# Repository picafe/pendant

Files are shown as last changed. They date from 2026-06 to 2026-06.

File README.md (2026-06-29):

# Bicolor LED Pendant

A pendant built from two PCBs: a 8×8 bicolor LED matrix module (red, orange, green) and controller board with battery charging, USB-C power, 5 V boost, and motion sensing.

## Why I made this

I had already been working on a 32×8 bicolor matrix module and wanted to try the Pendant YSWS before the deadline. An example on the pendant website inspired me to make a bicolor version with an orange fire-style pattern. Fitting the full matrix and controller on one 2/4 layer board was not the most possible, so my design splits into a display PCB and a pendant controller, which are connected with 2.54mm pitch pin headers (likely just male machine pin headers soldered on both sides, since they have a larger spacing to accomodate for the inductor). There is also an accelerometer to have potential particle motion simulation.

## Photos

### 3D model

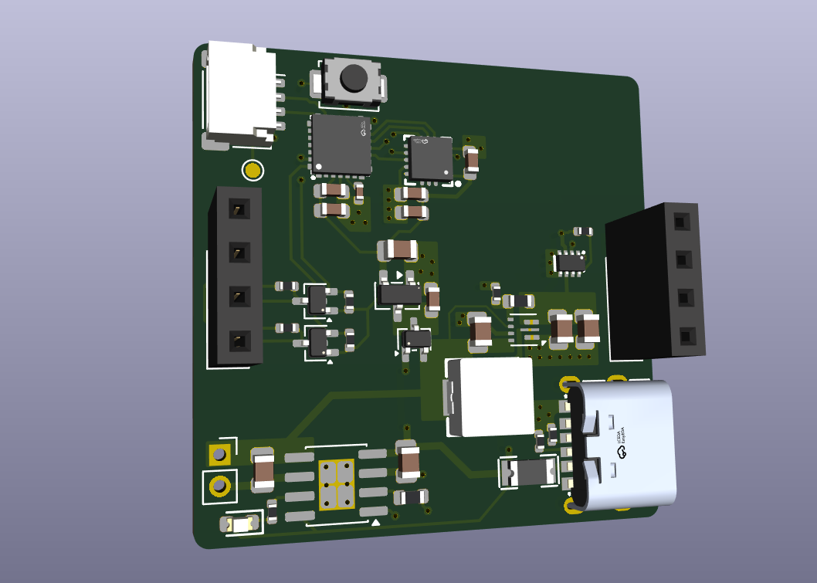
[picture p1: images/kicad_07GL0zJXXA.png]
Controller 3D model


### Schematic

**Controller**

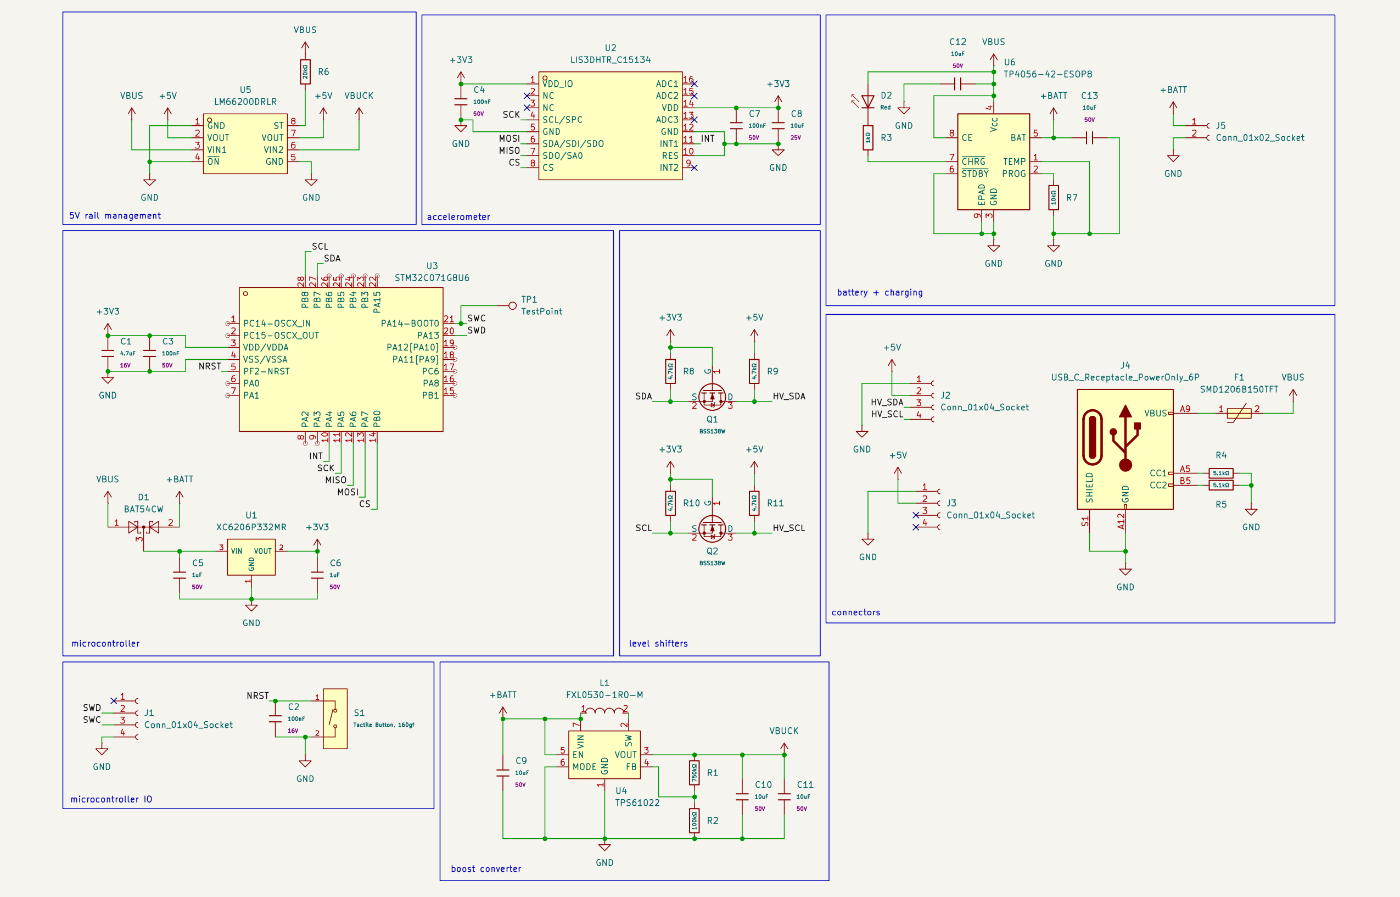
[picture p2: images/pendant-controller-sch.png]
Controller schematic


**Matrix**

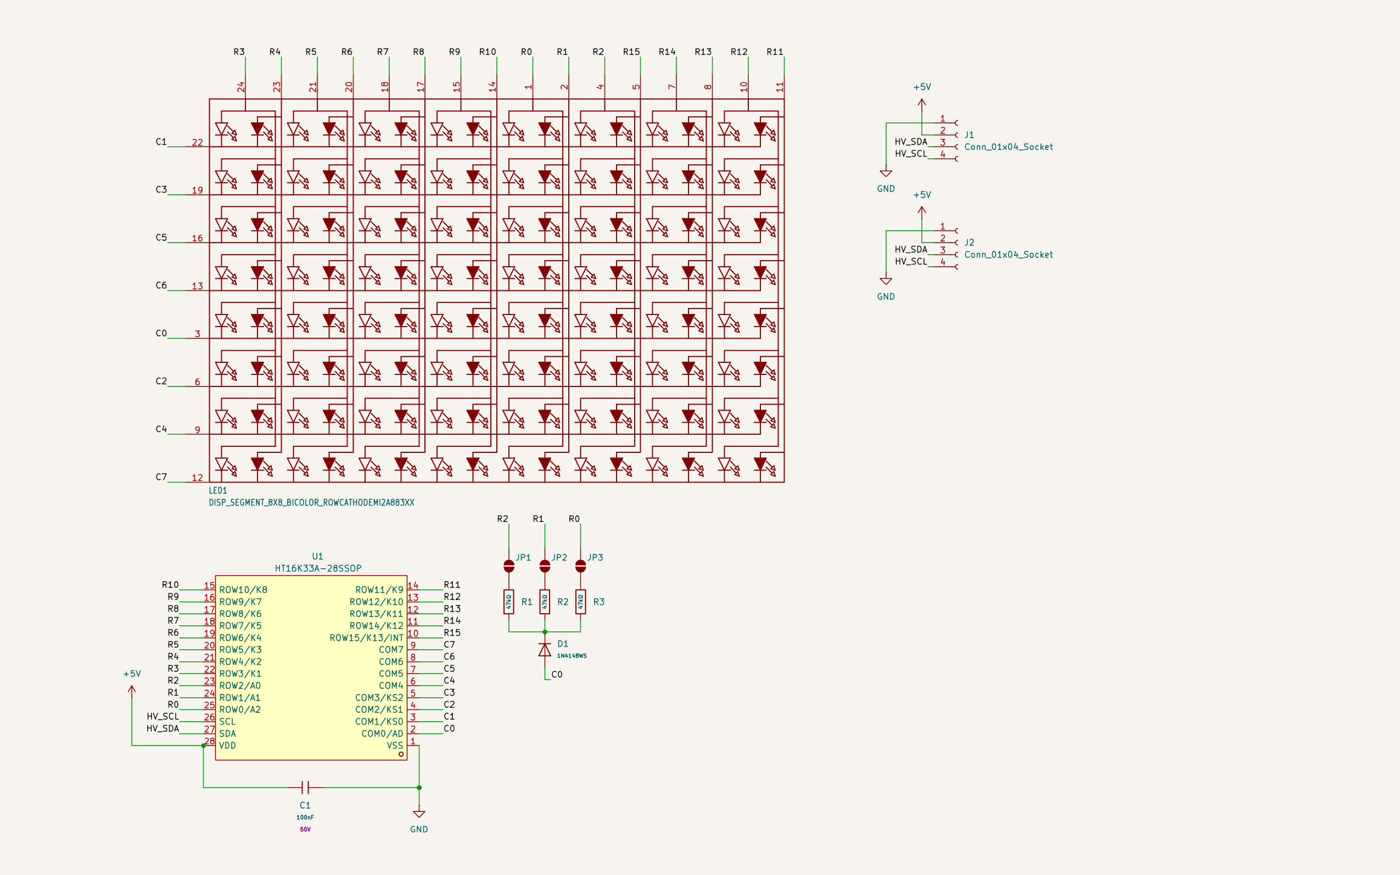
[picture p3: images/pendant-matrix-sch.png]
Matrix schematic


### PCB layouts

**Controller board**

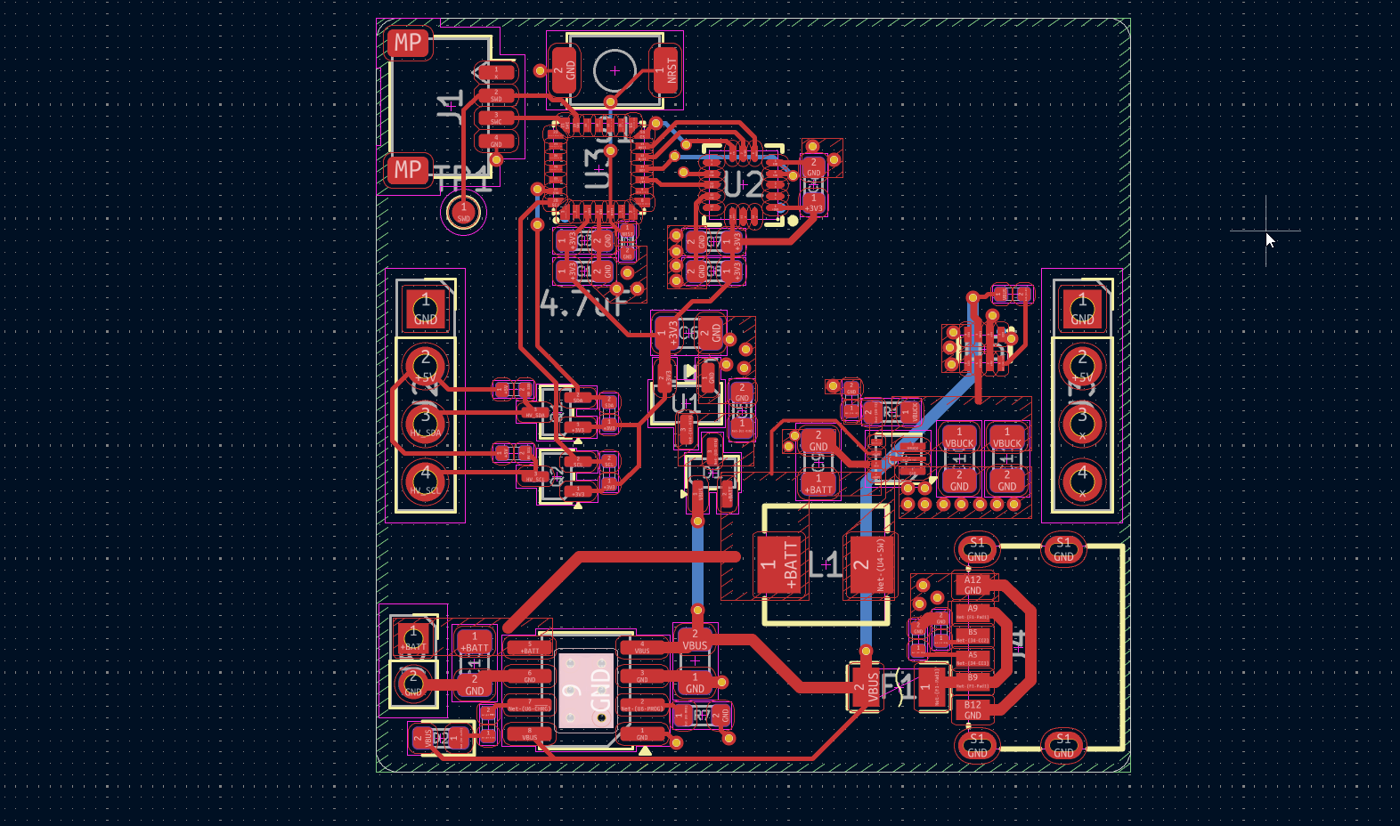
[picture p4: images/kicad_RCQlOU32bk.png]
Controller PCB routing


**Matrix module**

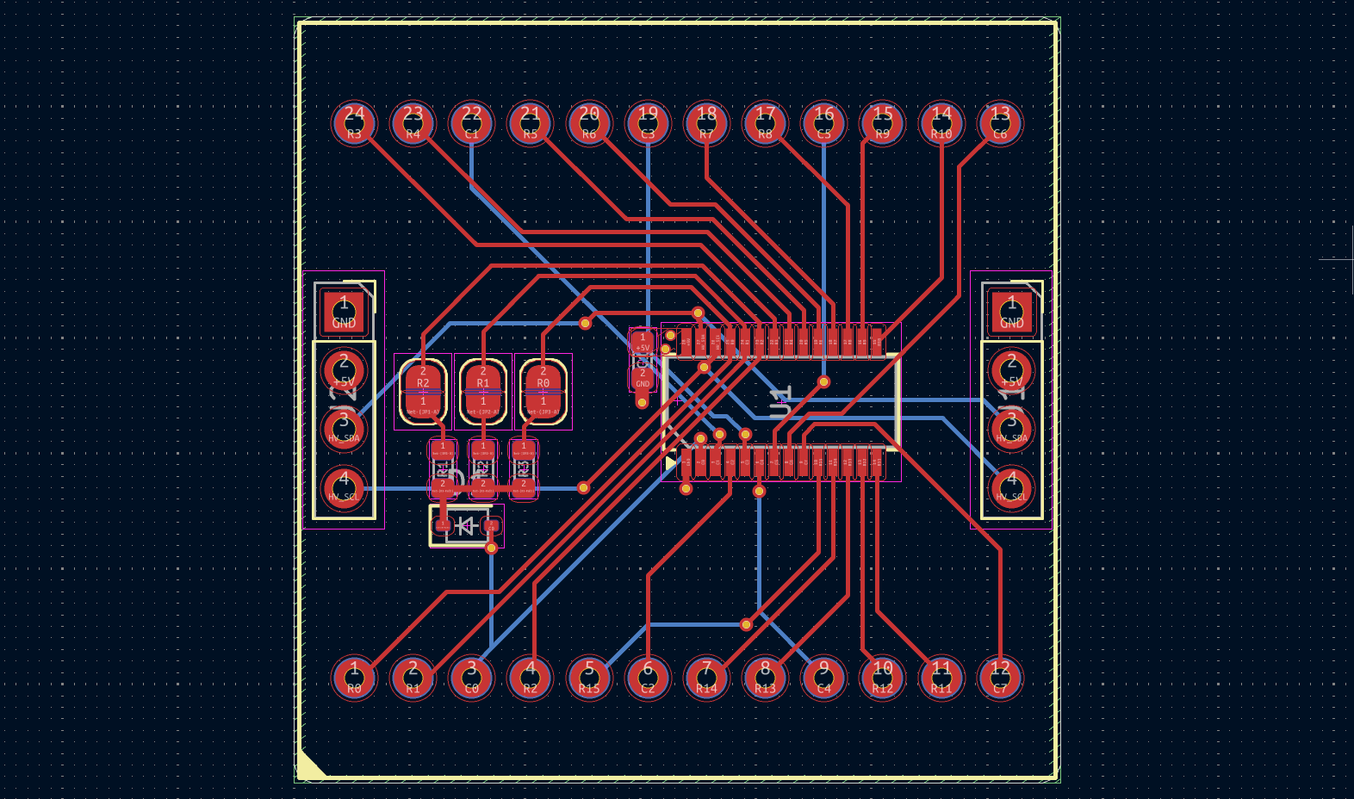
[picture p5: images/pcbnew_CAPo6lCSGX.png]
Matrix PCB layout


## Connections

All signals between the two boards are carried on PCB-mounted 2.54 mm pin headers. No off-board wiring is required beyond a LiPo cell on the controller.

## Bill of materials

Prices are per-unit LCSC values; standard connector values are estimated.

### Controller PCB

| Ref | Qty | Value | LCSC | Unit | Extended |
|-----|-----|---|---|---|---|
| U3 | 1 | STM32C071G8U6 | C44521811 | $1.67 | $1.67 |
| U4 | 1 | TPS61022 | C915088 | $1.32 | $1.32 |
| U5 | 1 | LIS2DW12TR | C189624 | $1.25 | $1.25 |
| U1 | 1 | XC6206P332MR | C5446 | $0.102 | $0.10 |
| U6 | 1 | TP4056-42-ESOP8 | C16581 | $0.19 | $0.19 |
| L1 | 1 | FXL0530-1R0-M | C475517 | $0.17 | $0.17 |
| Q1, Q2, Q3 | 3 | BSS138W | C28646265 | $0.025 | $0.08 |
| D1 | 1 | BAT54CW | C22392482 | $0.035 | $0.04 |
| D2 | 1 | Red LED | C2286 | $0.009 | $0.01 |
| D3 | 1 | SS34 | C8678 | $0.030 | $0.03 |
| F1 | 1 | SMD1206B150TFT | C269120 | $0.03 | $0.03 |
| S1 | 1 | Tactile button | C720477 | $0.053 | $0.05 |
| J4 | 1 | USB-C receptacle | C18357552 | $0.08 | $0.08 |
| J1 | 1 | JST-SH 4-pin | - | $0.08 *(est.)* | $0.08 |
| J2, J3 | 2 | 4-pin pin socket | - | $0.05 *(est.)* | $0.10 |
| J5 | 1 | 2-pin pin socket | - | $0.03 *(est.)* | $0.03 |
| C9–C13 | 5 | 10 µF | C440198 | $0.069 | $0.35 |
| C1 | 1 | 4.7 µF | C19666 | $0.014 | $0.01 |
| C8 | 1 | 10 µF | C96446 | $0.021 | $0.02 |
| C3, C4, C7 | 3 | 100 nF | C14663 | $0.006 | $0.02 |
| C5 | 1 | 1 µF | C15849 | $0.008 | $0.01 |
| C6 | 1 | 1 µF | C28323 | $0.012 | $0.01 |
| C2 | 1 | 100 nF | C1525 | $0.004 | $0.00 |
| R10–R11, R8–R9 | 4 | 4.7 kΩ | C25900 | $0.004 | $0.02 |
| R4, R5 | 2 | 5.1 kΩ | C25905 | $0.004 | $0.01 |
| R2, R6 | 2 | 100 kΩ | C25741 | $0.004 | $0.01 |
| R1 | 1 | 750 kΩ | C23240 | $0.004 | $0.00 |
| R3 | 1 | 1 kΩ | C11702 | $0.004 | $0.00 |
| R7 | 1 | 10 kΩ | C25804 | $0.004 | $0.00 |
| R12 | 1 | 10 kΩ | C25744 | $0.004 | $0.00 |
| R13 | 1 | 120 Ω | C25079 | $0.004 | $0.00 |

**Controller subtotal: $5.71**

### Matrix PCB

| Ref | Qty | Value | LCSC | Unit | Extended |
|-----|-----|---|---|---|---|
| U1 | 1 | HT16K33A-28SSOP | C5444738 | $0.50 | $0.50 |
| LED1 | 1 | 8×8 bicolor LED matrix | - | $1.50 *(est.)* | $1.50 |
| R1–R3 | 3 | 47 kΩ | C25819 | $0.004 | $0.01 |
| C1 | 1 | 100 nF | C14663 | $0.006 | $0.01 |
| D1 | 1 | 1N4148WS | C2128 | $0.012 | $0.01 |
| J1, J2 | 2 | 4-pin pin socket | - | $0.05 *(est.)* | $0.10 |

**Matrix subtotal: $2.13**

### Total component cost

| Board | Subtotal |
|---|---|
| Controller | $5.71 |
| Matrix | $2.13 |
| **Grand total (1× each board)** | **$7.84** |

*Does not include PCB fabrication, shipping, LiPo battery, or assembly fees.*

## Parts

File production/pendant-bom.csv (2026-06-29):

Designator | Footprint | Quantity | Value | LCSC Part #
C1 | C_0603 | 1 | 4.7uF | C19666
C10, C11, C12, C13, C9 | C_0805 | 5 | 10uF | C440198
C2 | C_0402 | 1 | 100nF | C1525
C3, C4, C7 | C_0603 | 3 | 100nF | C14663
C5 | C_0603 | 1 | 1uF | C15849
C6 | C_0805 | 1 | 1uF | C28323
C8 | C_0603 | 1 | 10uF | C96446
D1 | SOT-323_SC-70 | 1 | BAT54CW | C22392482
D2 | D_0603 | 1 | Red | C2286
D3 | D_SMA | 1 | SS34 | C8678
F1 | F1206 | 1 | SMD1206B150TFT | C269120
J1 | JST_SH_SM04B-SRSS-TB_1x04-1MP_P1.00mm_Horizontal | 1 | Conn_01x04_Socket
J2, J3 | PinSocket_1x04_P2.54mm_Vertical | 2 | Conn_01x04_Socket
J4 | USB-C-SMD_HX-TYPE-C-6PIN | 1 | USB_C_Receptacle_PowerOnly_6P | C18357552
J5 | PinSocket_1x02_P2.00mm_Vertical | 1 | Conn_01x02_Socket
L1 | IND-SMD_L5.4-W5.2_FXL0530 | 1 | FXL0530-1R0-M | C475517
Q1, Q2, Q3 | SOT-323_SC-70 | 3 | BSS138W | C28646265
R1 | R_0603 | 1 | 750kΩ | C23240
R10, R11, R8, R9 | R_0402 | 4 | 4.7kΩ | C25900
R12 | R_0402 | 1 | 10kΩ | C25744
R13 | R_0402 | 1 | 120Ω | C25079
R2, R6 | R_0402 | 2 | 100kΩ | C25741
R3 | R_0402 | 1 | 1kΩ | C11702
R4, R5 | R_0402 | 2 | 5.1kΩ | C25905
R7 | R_0603 | 1 | 10kΩ | C25804
S1 | SW_SPST_TS-1088-xR020 | 1 | Tactile Button, 160gf | C720477
TP1 | TestPoint_Pad_D1.0mm | 1 | TestPoint
U1 | SOT-23-3 | 1 | XC6206P332MR | C5446
U3 | QFN-28_L4.0-W4.0-P0.50-TL | 1 | STM32C071G8U6 | C44521811
U4 | Texas_RWU0007A_VQFN-7_2x2mm_P0.5mm | 1 | TPS61022 | C915088
U5 | LGA-12_L2.0-W2.0-P0.50-BL | 1 | LIS2DW12TR | C189624
U6 | SOIC-8-1EP_3.9x4.9mm_P1.27mm_EP2.41x3.3mm_ThermalVias | 1 | TP4056-42-ESOP8 | C16581

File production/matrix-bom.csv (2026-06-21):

Designator | Footprint | Quantity | Value | LCSC Part #
C1 | C_0603 | 1 | 100nF | C14663
D1 | D_SOD-323 | 1 | 1N4148WS | C2128
J1, J2 | PinSocket_1x04_P2.54mm_Vertical | 2 | Conn_01x04_Socket
LED1 | SEGMENT_BICOL_BL-M12A883XX | 1 | DISP_SEGMENT_8X8_BICOLOR_ROWCATHODEMI2A883XX
R1, R2, R3 | R_0603 | 3 | 47kΩ | C25819
U1 | SSOP-28_3.9x9.9mm_P0.635mm | 1 | HT16K33A-28SSOP | C5444738

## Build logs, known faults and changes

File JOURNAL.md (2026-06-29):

# June 18: Started project and schematic

I discovered today that the pendant YSWS ends today (tomorrow my timezone), so I quickly thought of something I could rush in that timeframe. I had been working on a 32x8 bicolor matrix module, which is just 4 modules combined into a board. After looking at the pendant homepage, I got inspired by the example and decided to make a pendant similar to that but with a three colour display instead (red, orange, green). I thought of using 1 pcb for the entire thing, but that likely wasn't possible as 2 layers was mostly needed for the matrix routing and address selection. So, I decided to go with the same method of having an adapter board with a controller. It would be pretty cool to have an orange fire pattern.

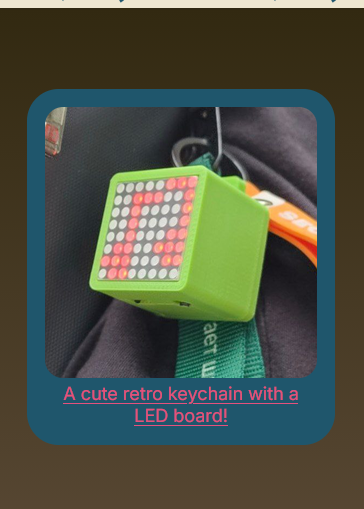
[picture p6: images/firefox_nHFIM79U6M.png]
website inspiration

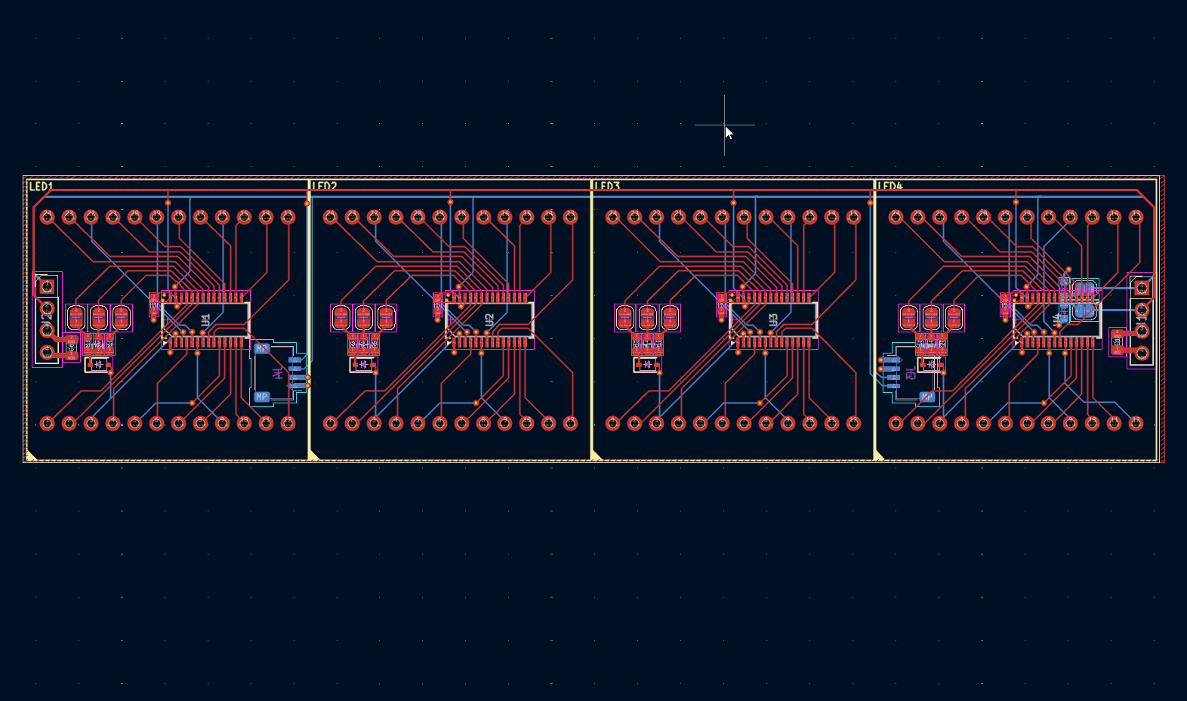
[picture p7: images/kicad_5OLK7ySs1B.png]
kicad schematic start


I mostly worked on the schematic, trying to get all the components in and routed. I browsed WEBENCH for a good boost converter to use, since the display needed 5V to operate (green LEDs, not really reliable with VBAT supply for a lipo cell). Although I would need 2 different boards, separating them into their own schematic would be fairly easy. I wanted to focus my attention onto getting everything connected and assign footprints.

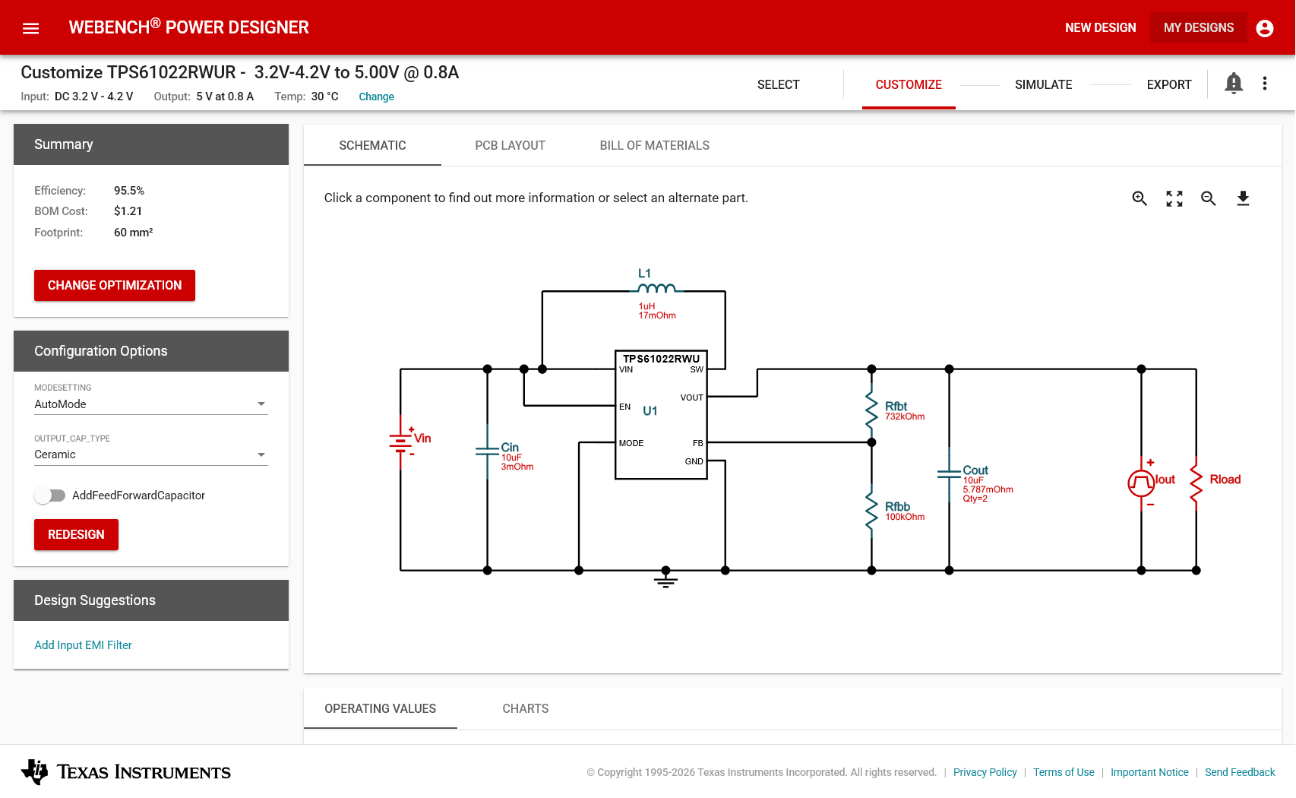
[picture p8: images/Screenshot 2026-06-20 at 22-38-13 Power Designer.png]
WEBENCH power designer

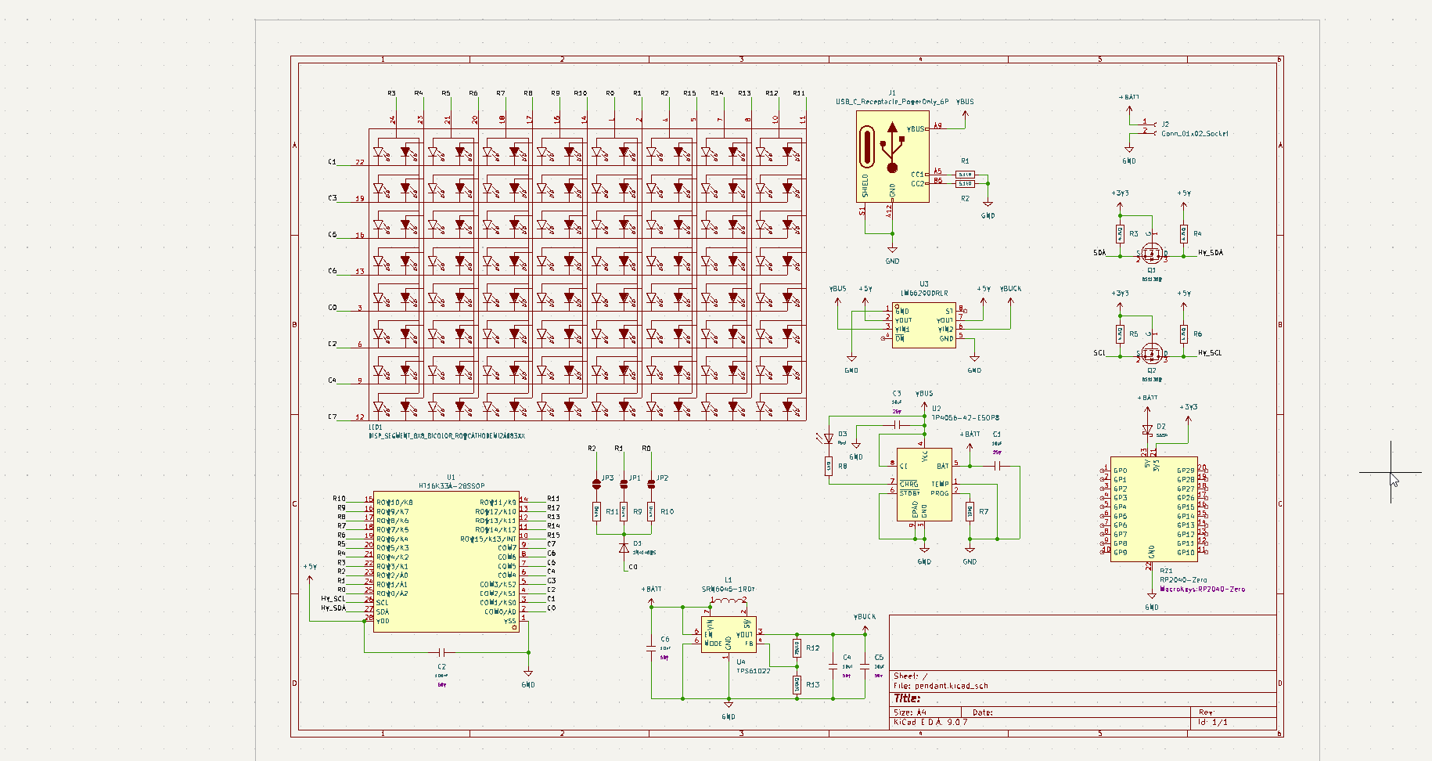
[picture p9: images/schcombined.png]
combined schematic


Total time spent: 2.5 hours

# June 19: Split into two PCBs and started layout

I began the day by separating the project into 2 pcbs, the matrix module and the pendant controller. The PCB was just a matter of copying the traces and vias from my 32x8 matrix and adjusting a few traces and vias to fit the new board. Overall, it took about 1.5hrs to complete this section.
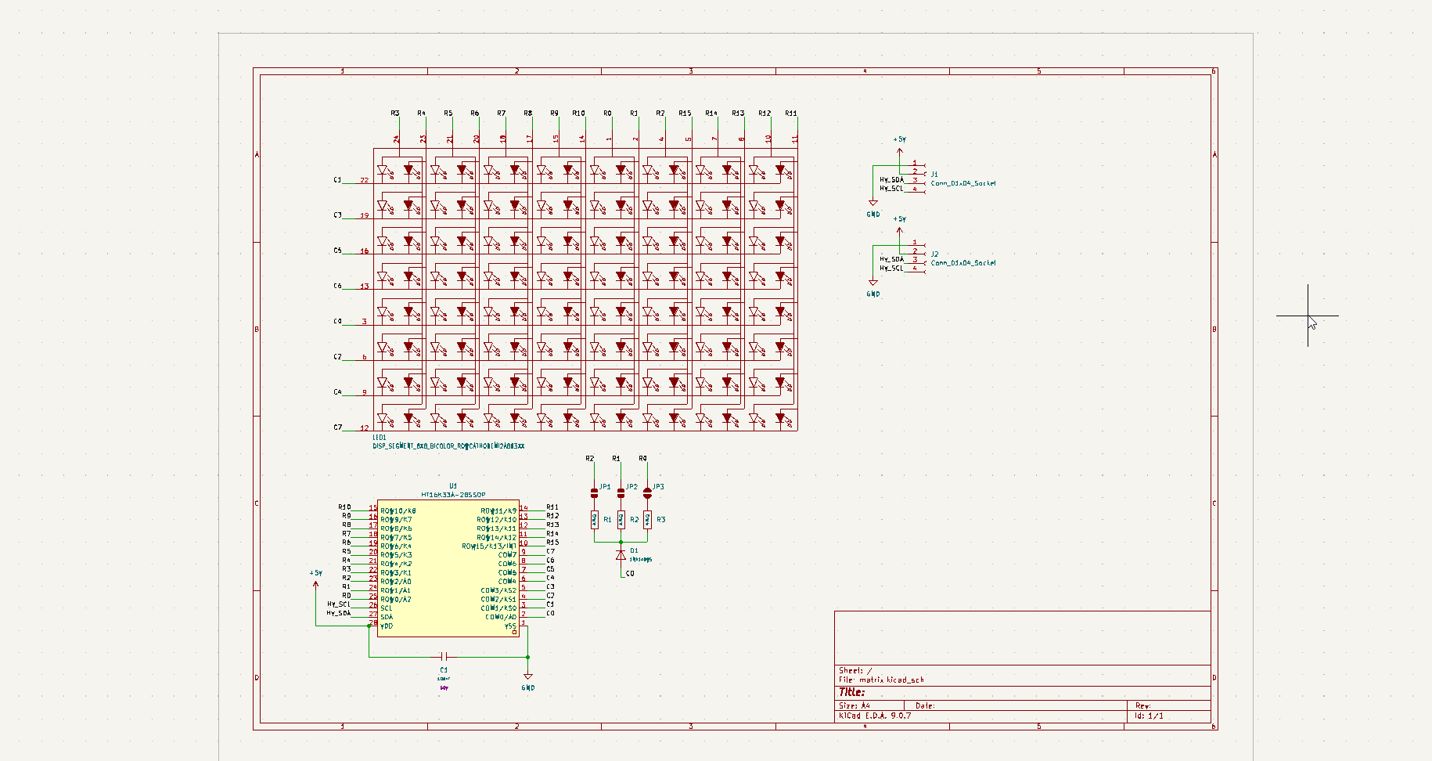
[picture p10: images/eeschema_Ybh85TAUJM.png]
matrix schematic

matrix pcb layout

However, the challenge came when I tried to import the changes into PCB for the pendant controller. I originally wanted to use a RP2040 Zero (the one without the USB connector), since it could be surface mounted without a bottom cutout on the board. However, it seems like this won't be possible with my board size. 

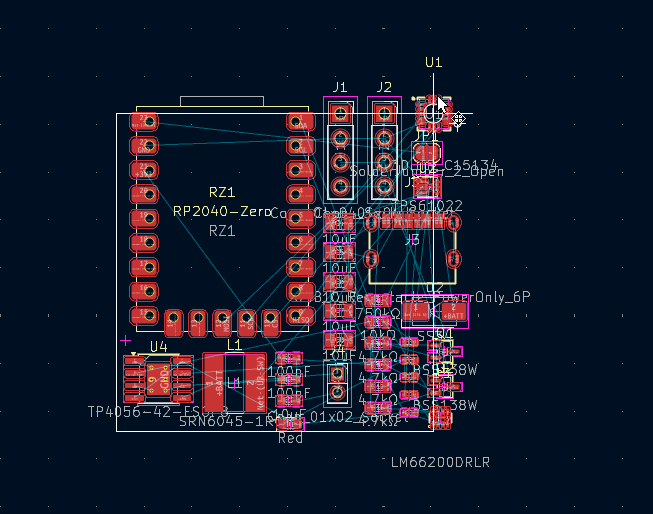
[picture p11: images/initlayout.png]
controller initial layout


I wanted a small but simple solution, since I didn't want to spend too much time on this project. I thought back to the Arduino modulino modules which I had looked at a while ago. They're quite comical to me, especially the button and buzzer modules, which literally use a STM32 microcontroller to breakout 4 buttons and 1 buzzer respectively over I2C. They use the STM32C011, which is a very small microcontroller that doesn't need any external components other than decoupling capacitors. This would be too small for my application, since I wanted to use Arduino IDE and heavy Adafruit GFX libraries (along with STM32 Arduino Core). So, I settled with STM32C071. After finishing, I started working on the boost converter layout:

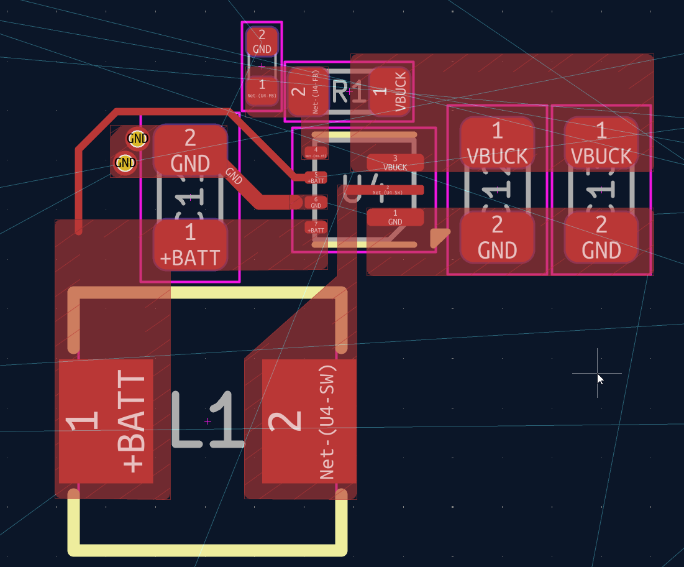
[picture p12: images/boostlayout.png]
boost converter layout


This took a while since I kept having to adjust the clearance to keep the routing possible to what the datasheet recommended. I ended up with 0.2mm clearance from track/pour to pad, which is quite tight but should be fine.

As I was laying out the components and talking to a friend, they asked if what I was making was one of those particle motion simulation display matrices. I sent him a video of one a while ago, so I guess he thought it was that. This gave me the inspo to add an accelerometer to the controller, so I spent ~20 mins searching for an accelerometer. I initially thought of LIS2DW12, but it's  only under standard assembly. Thankfully, LIS3DH is under economic, so I went with that. 

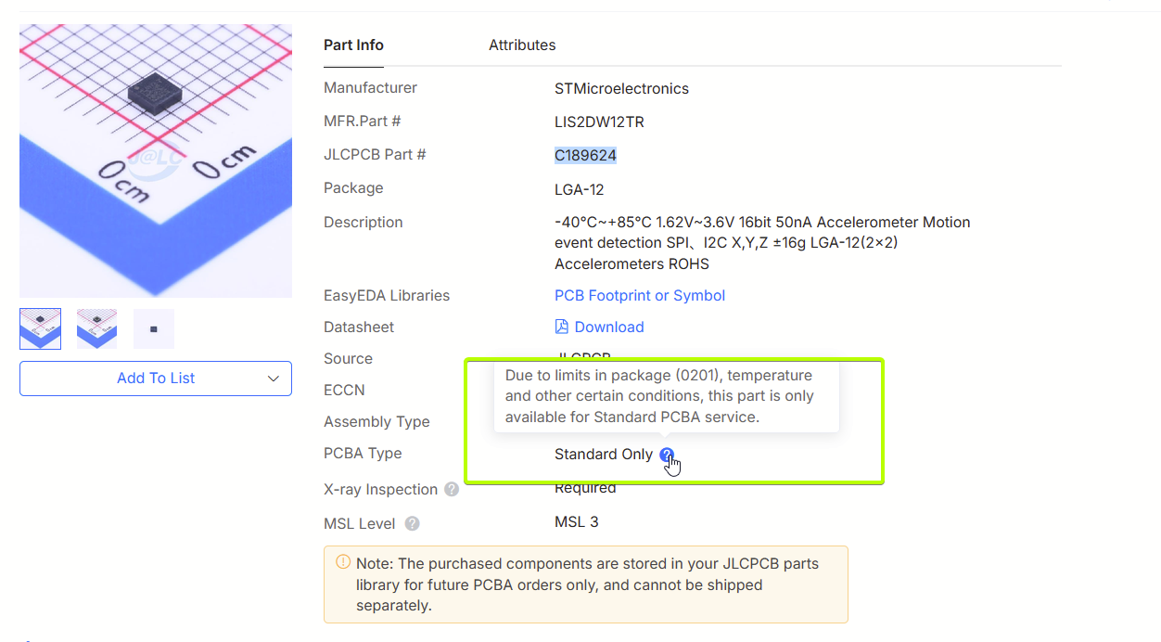
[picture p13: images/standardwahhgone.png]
accelerometer part selection


Progress after laying out the components and some routing:

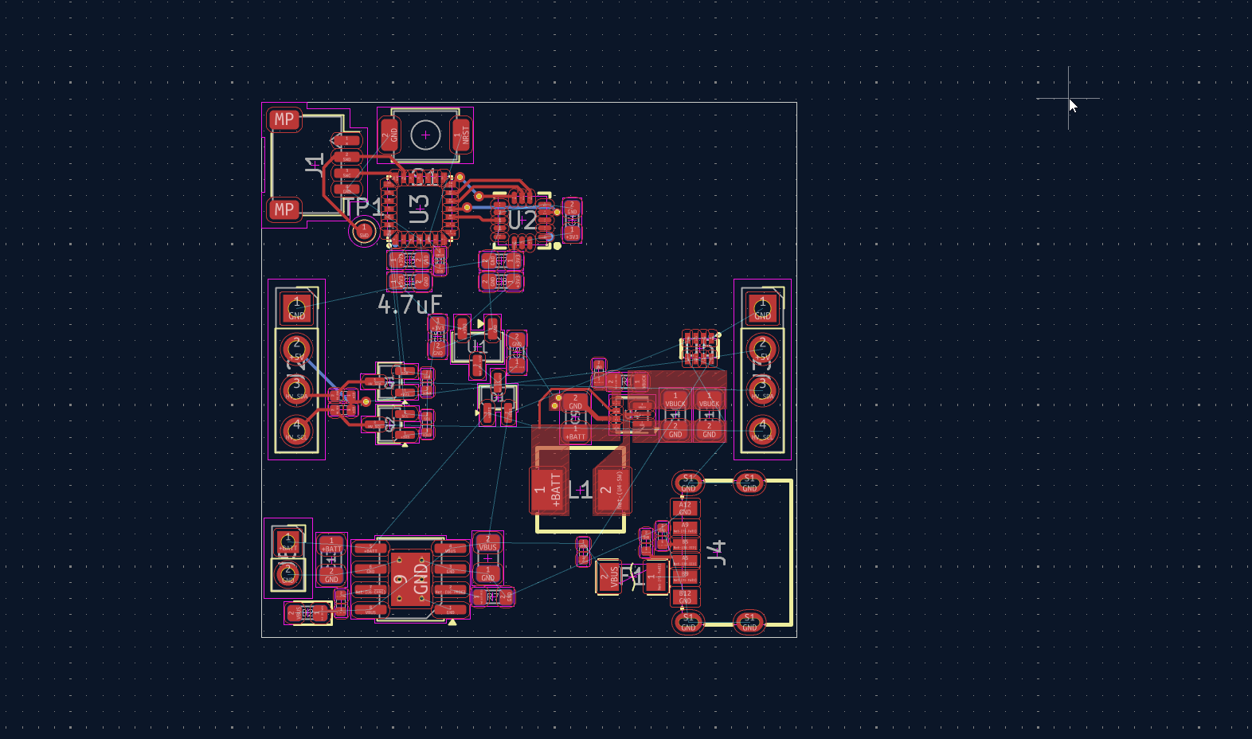
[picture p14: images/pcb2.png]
controller pcb progress


Although it's now past the Pendant deadline, I wanted to finish this, and it gave me more motivation to spend time polishing the routing. 

Total time spent: 5 hours

# June 20: Finished routing and cleaned up schematic

I very much locked in on the routing and spent a few hours getting everything pretty much finished. 

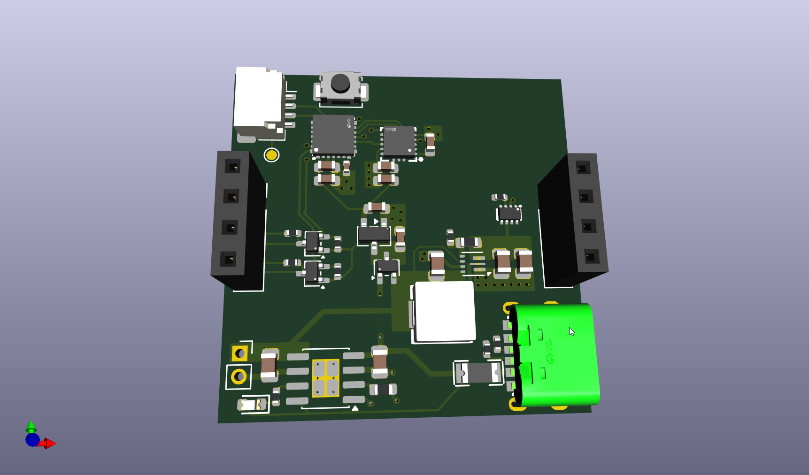
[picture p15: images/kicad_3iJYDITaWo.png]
finished pcb routing


DRC had a few errors about the USB C port, although most were about the footprint of the QFN-28 4x4 footprint from JLC. I just decided to ignore them for now, since it should be fine and within JLC tolerances (esp since it's the JLC footprint). 

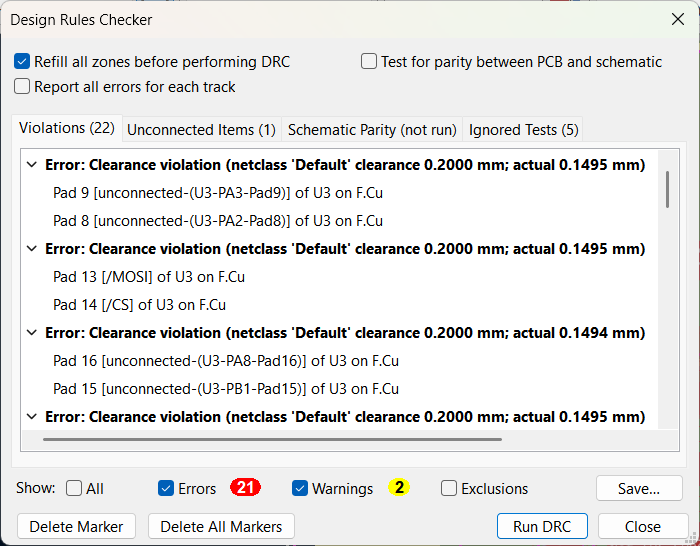
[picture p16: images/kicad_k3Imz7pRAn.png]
DRC check results


final routing

Finally, I spent some time cleaning up the schematic:

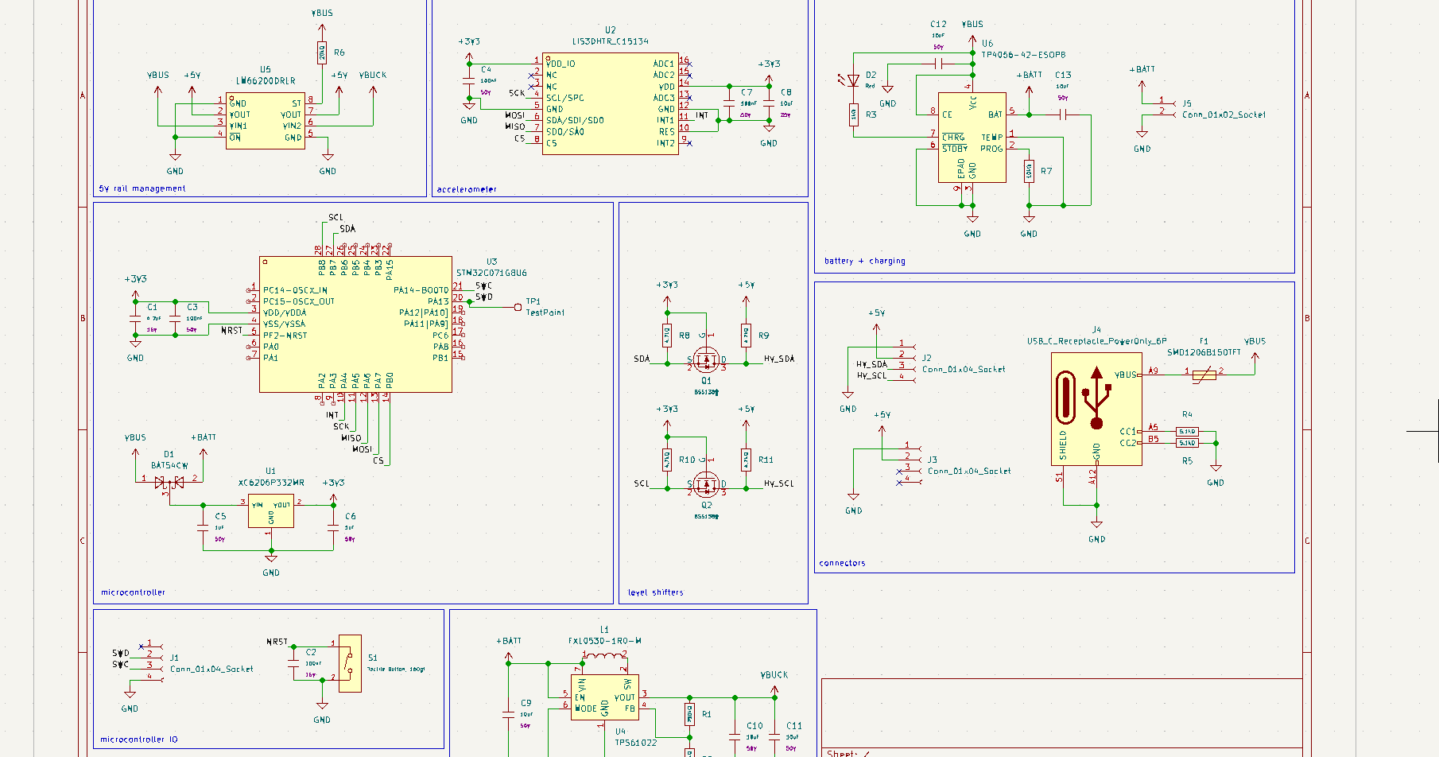
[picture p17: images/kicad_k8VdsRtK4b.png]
cleaned up schematic


Total time spent: 4 hours

# June 24: Revision of power management system

Looking at my circuit again, I realized a small (not that small) flaw. Since I choose the LM66200, which is a dual ideal diode, it would always select the input from the higher voltage input. Since I am only using standard components for my resistors, I'm using a 750k resistor currently for my feedback resistor, resulting in 5.1V output. This would mean that the USB would never actually power anything. I thought of using the TPS2116 instead, which is the same IC but is a dual input MUX, but I just figured I could just have the USB input (VBUS) turn off the boost converter, and add a diode on the USB input to prevent reverse current. This is what I decided to go with, and made the quick adjustments:

Enbale circuit for the boost converter (EN high, so used a N-MOSFET)
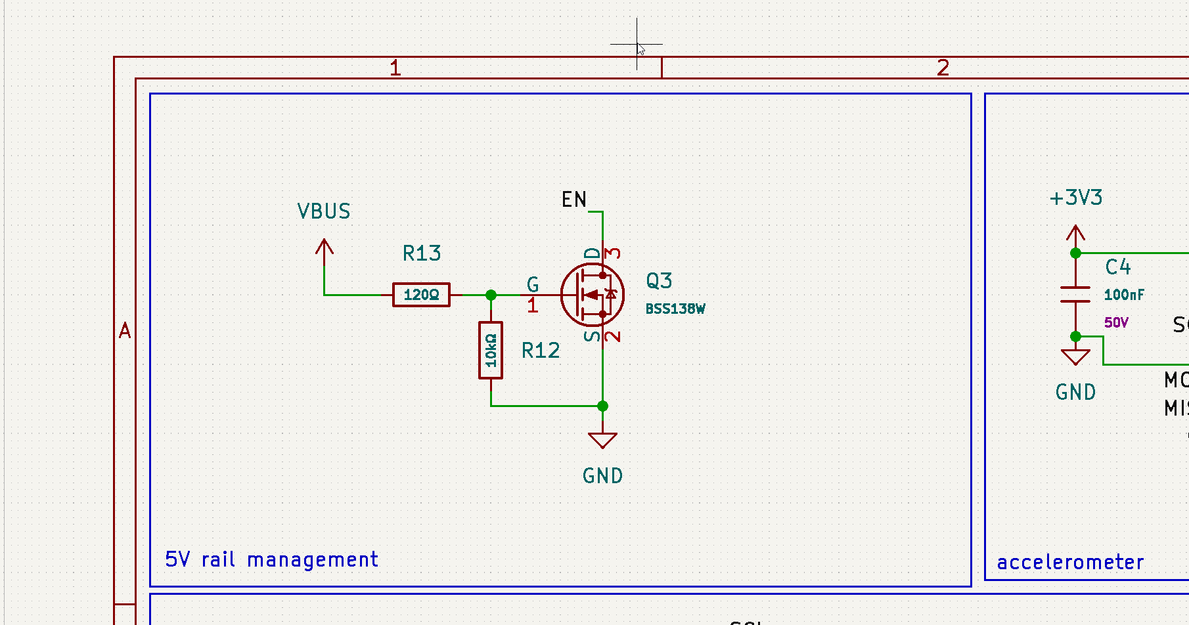
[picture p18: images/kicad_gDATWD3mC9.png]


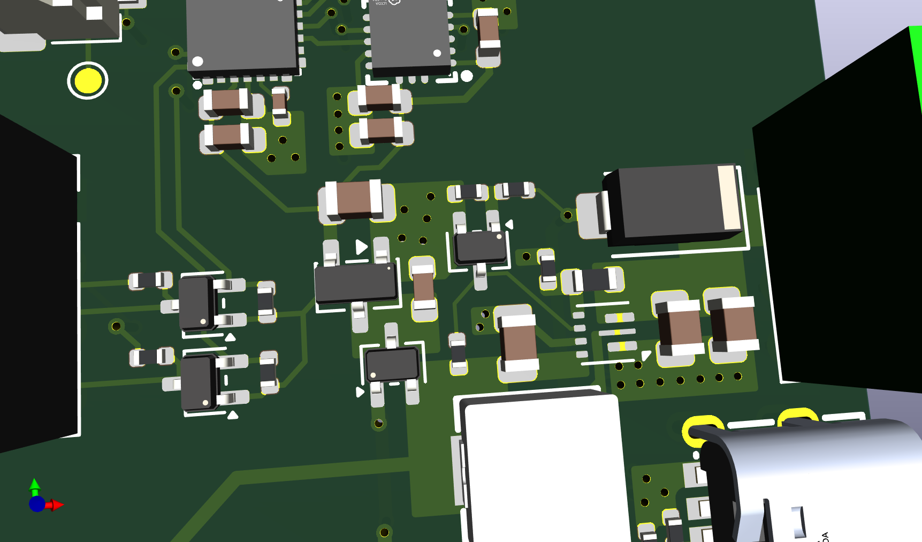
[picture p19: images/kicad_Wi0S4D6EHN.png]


Total time spent: 2 hours

# June 26: Accelerometer change

I decided that I was going to hand assemble the non-basic parts and only get the basic parts assembled. I originally chose it based on the fact that it was one of the good ones that supported economic assembly (and not standard only). After checking, its stock is unreliable on LCSC, so I decided to change it to the LIS2DW12, which is newer and better (and more widely available), but has a different FP and pinout, which made it annoying to route. 

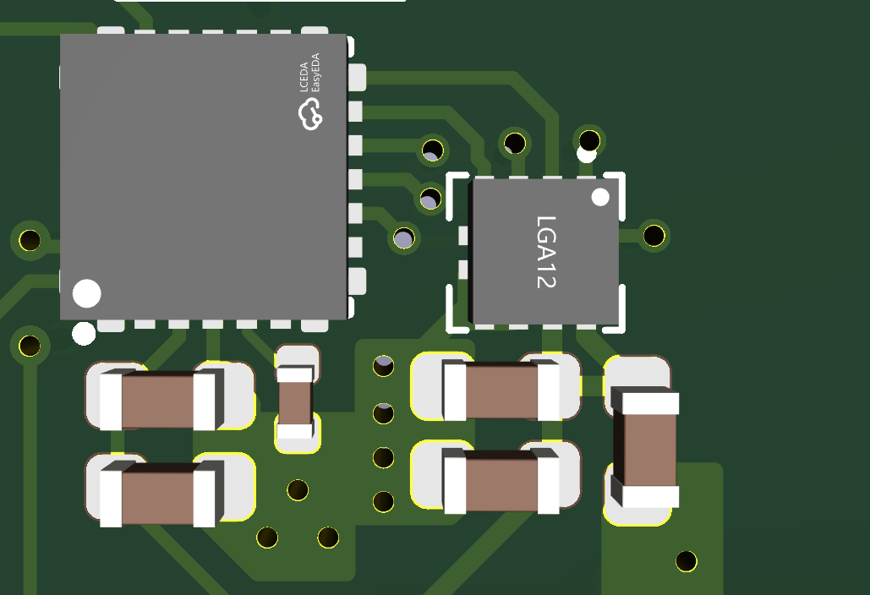
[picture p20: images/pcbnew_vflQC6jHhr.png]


Total time spent: 1 hour

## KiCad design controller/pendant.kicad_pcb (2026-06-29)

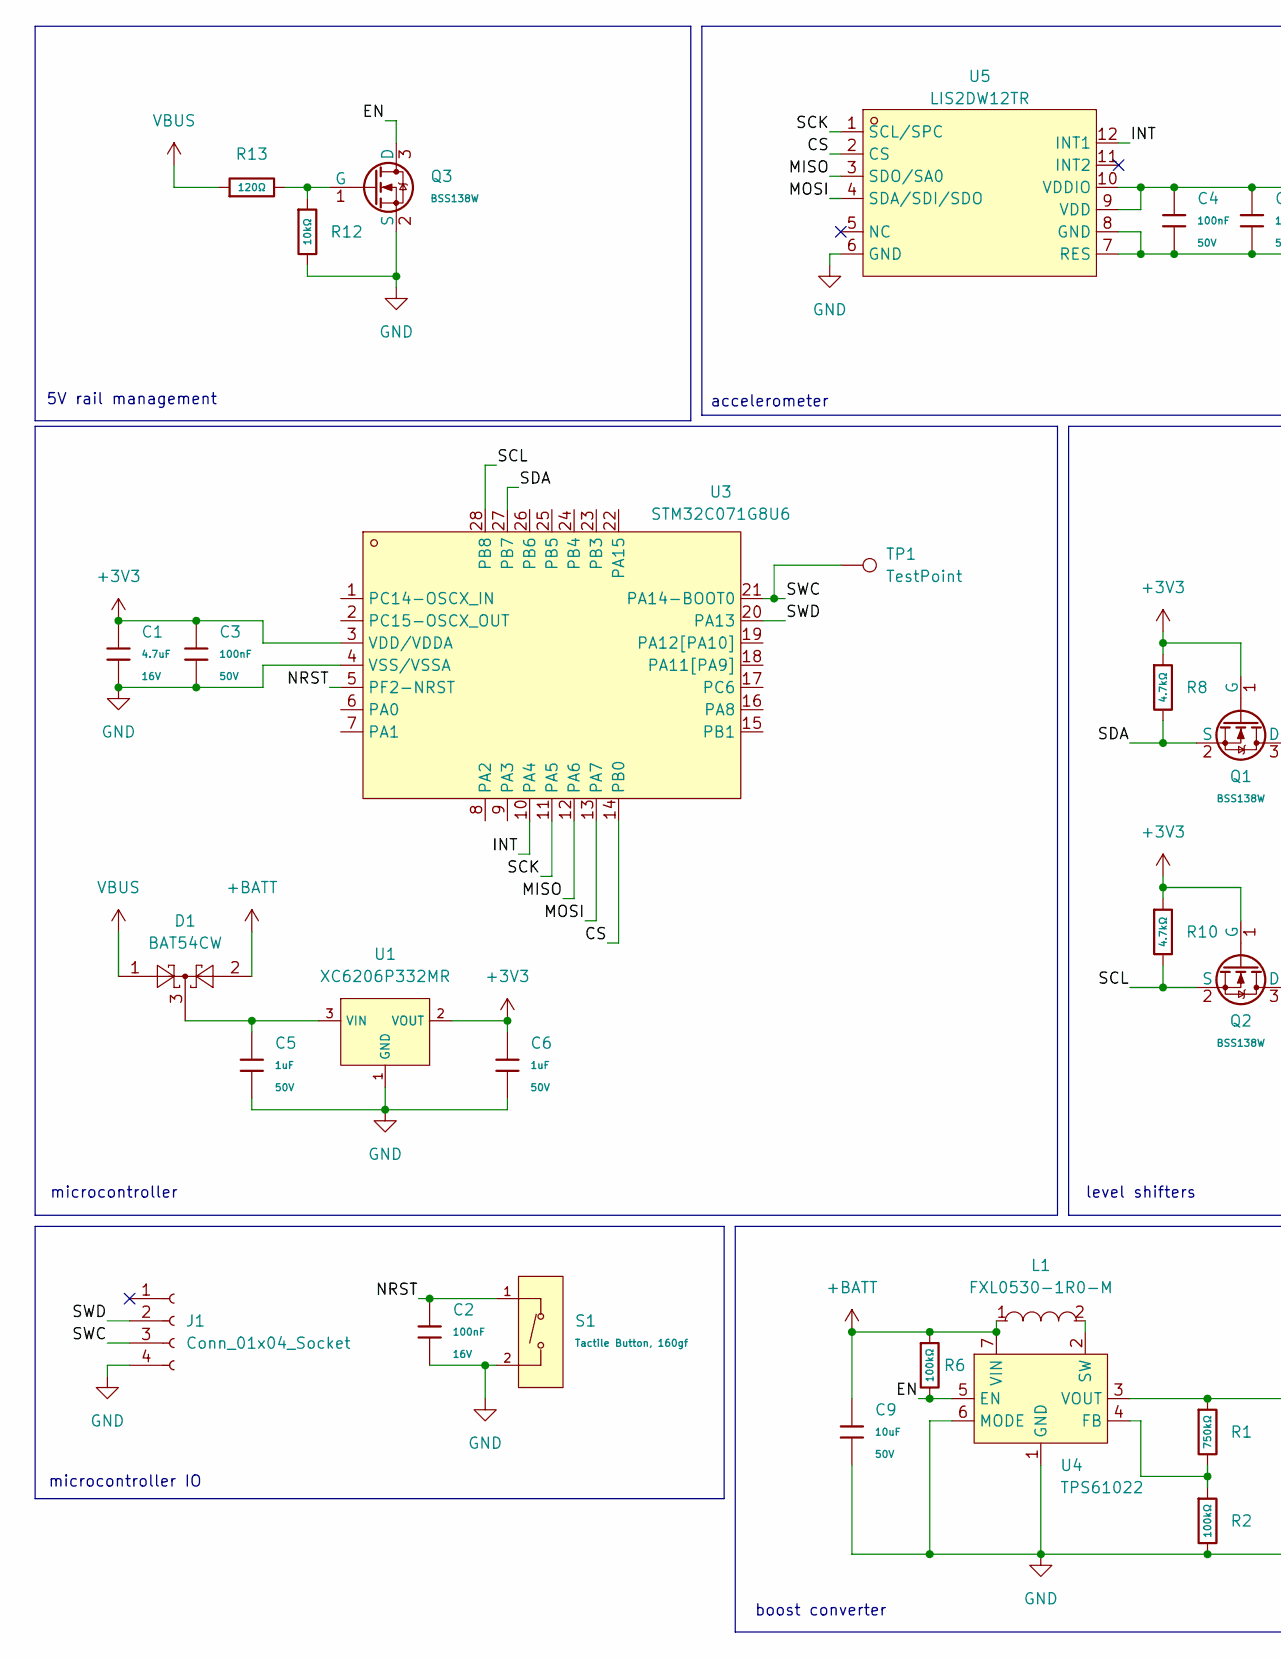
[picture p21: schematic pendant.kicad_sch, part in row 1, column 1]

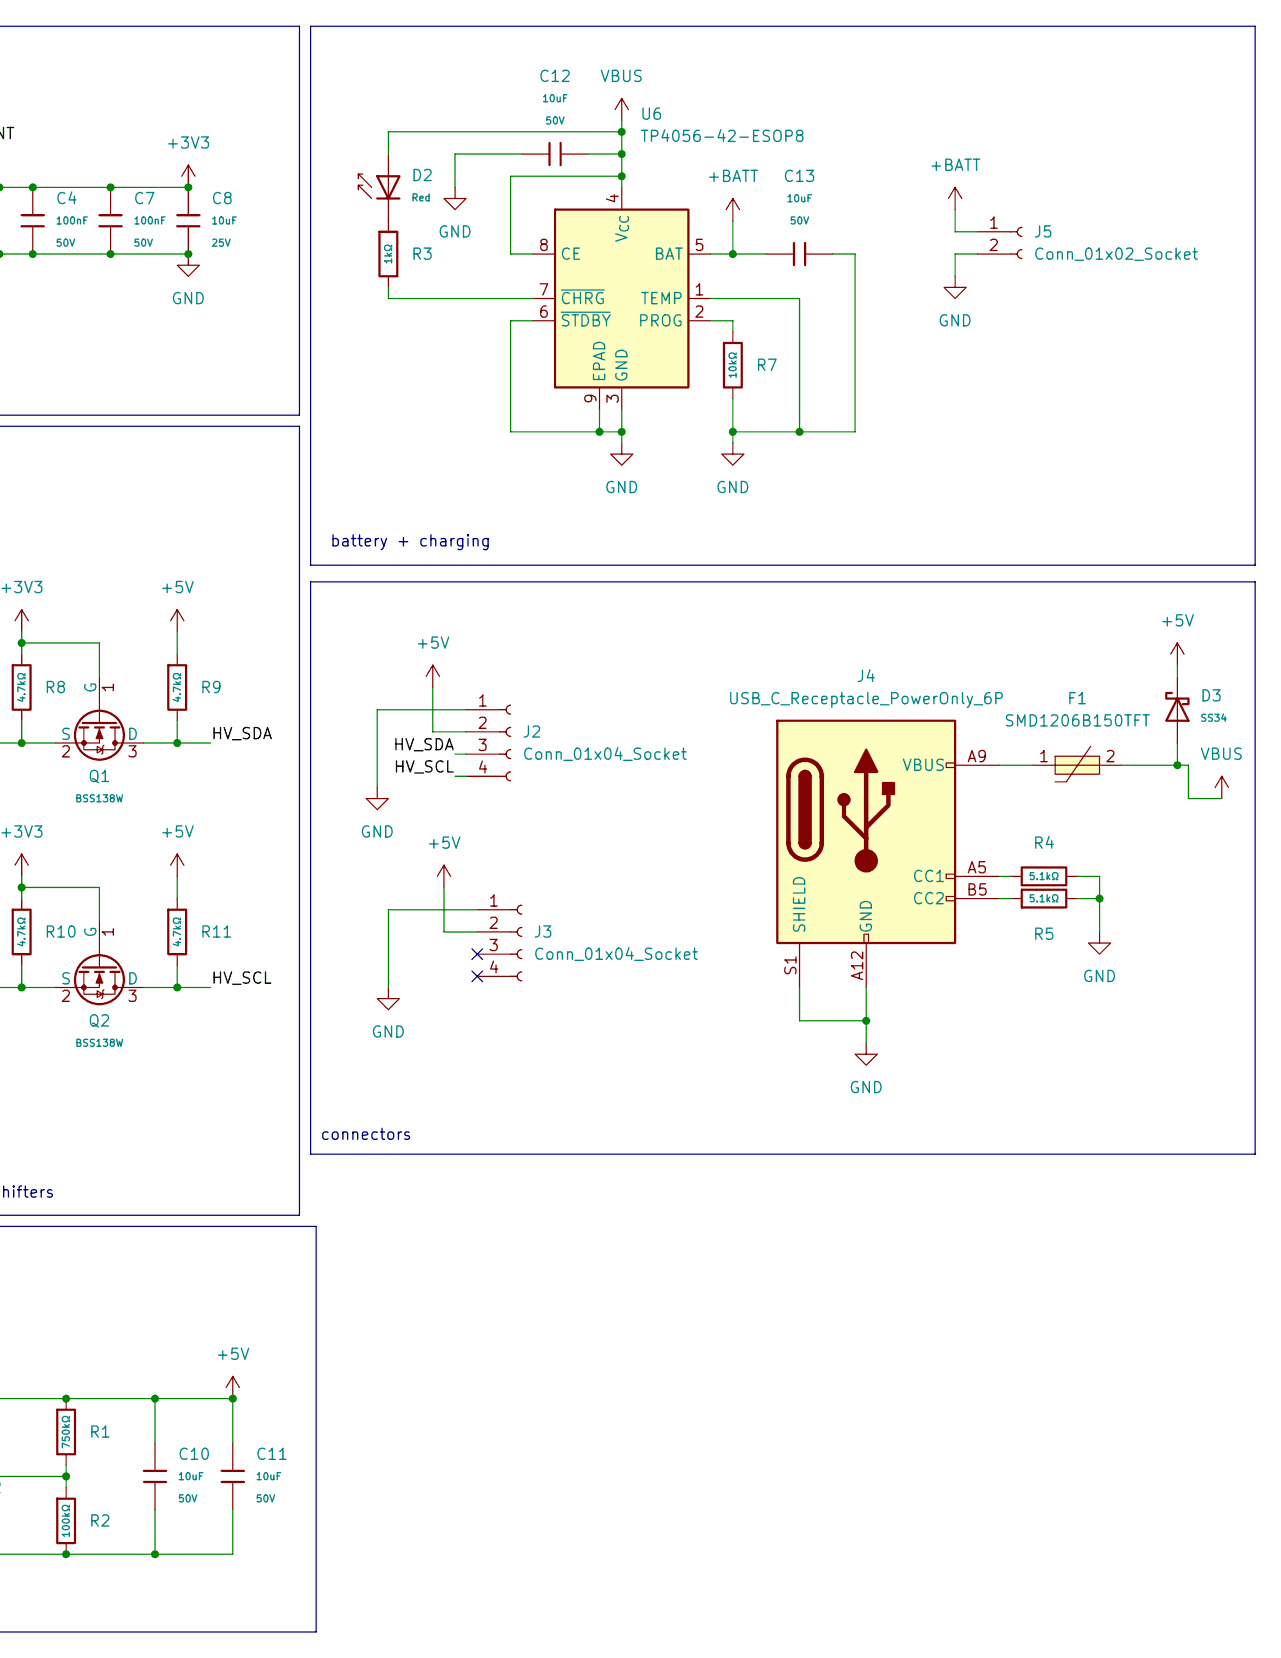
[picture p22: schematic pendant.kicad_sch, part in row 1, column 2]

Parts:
C1: 4.7uF; C_0603; Voltage Rated 16V; Tolerance ±10%; Part CL10A475KO8NNNC; LCSC C19666
C2: 100nF; C_0402; Voltage Rated 16V; Tolerance ±10%; Part CL05B104KO5NNNC; LCSC C1525
C3, C4, C7: 100nF; C_0603; Voltage Rated 50V; Tolerance ±10%; Part CC0603KRX7R9BB104; LCSC C14663
C5: 1uF; C_0603; Voltage Rated 50V; Tolerance ±10%; Part CL10A105KB8NNNC; LCSC C15849
C6: 1uF; C_0805; Voltage Rated 50V; Tolerance ±10%; Part CL21B105KBFNNNE; LCSC C28323
C8: 10uF; C_0603; Voltage Rated 25V; Tolerance ±20%; Part CL10A106MA8NRNC; LCSC C96446
C9, C10, C11, C12, C13: 10uF; C_0805; Voltage Rated 50V; Tolerance ±10%; Part GRM21BR61H106KE43L; LCSC C440198
D1: BAT54CW; SOT-323_SC-70; LCSC C22392482
D2: Red; D_0603; Part KT-0603R; LCSC C2286
D3: SS34; D_SMA; Forward Voltage (Vf@If) 550mV@3A; Reverse Voltage (Vr) 40V; Part SS34; LCSC C8678
F1: SMD1206B150TFT; F1206; MPN SMD1206B150TFT; LCSC Part C269120
J1: Conn_01x04_Socket; JST_SH_SM04B-SRSS-TB_1x04-1MP_P1.00mm_Horizontal
J2, J3: Conn_01x04_Socket; PinSocket_1x04_P2.54mm_Vertical
J4: USB_C_Receptacle_PowerOnly_6P; USB-C-SMD_HX-TYPE-C-6PIN; LCSC C18357552
J5: Conn_01x02_Socket; PinSocket_1x02_P2.00mm_Vertical
L1: FXL0530-1R0-M; IND-SMD_L5.4-W5.2_FXL0530; MPN FXL0530-1R0-M; LCSC Part C475517
Q1, Q2, Q3: BSS138W; SOT-323_SC-70; Part BSS138W; LCSC C28646265
R1: 750kΩ; R_0603; Overload Voltage (Max) 75V; Tolerance ±1%; Part 0603WAF7503T5E; LCSC C23240
R2, R6: 100kΩ; R_0402; Overload Voltage (Max) 50V; Tolerance ±1%; Part 0402WGF1003TCE; LCSC C25741
R3: 1kΩ; R_0402; Overload Voltage (Max) 50V; Tolerance ±1%; Part 0402WGF1001TCE; LCSC C11702
R4, R5: 5.1kΩ; R_0402; Overload Voltage (Max) 50V; Tolerance ±1%; Part 0402WGF5101TCE; LCSC C25905
R7: 10kΩ; R_0603; Overload Voltage (Max) 75V; Tolerance ±1%; Part 0603WAF1002T5E; LCSC C25804
R8, R9, R10, R11: 4.7kΩ; R_0402; Overload Voltage (Max) 50V; Tolerance ±1%; Part 0402WGF4701TCE; LCSC C25900
R12: 10kΩ; R_0402; Overload Voltage (Max) 50V; Tolerance ±1%; Part 0402WGF1002TCE; LCSC C25744
R13: 120Ω; R_0402; Overload Voltage (Max) 50V; Tolerance ±1%; Part 0402WGF1200TCE; LCSC C25079
S1: Tactile Button, 160gf; SW_SPST_TS-1088-xR020; Voltage Rating (Dc) 12V; Part TS-1088-AR02016; LCSC C720477
TP1: TestPoint; TestPoint_Pad_D1.0mm
U1: XC6206P332MR; SOT-23-3; Output Voltage 3.3V; Dropout Voltage 680mV@(100mA); Part XC6206P332MR-G; LCSC C5446
U3: STM32C071G8U6; QFN-28_L4.0-W4.0-P0.50-TL; MPN STM32C071G8U6; LCSC Part C44521811
U4: TPS61022; Texas_RWU0007A_VQFN-7_2x2mm_P0.5mm; LCSC C915088
U5: LIS2DW12TR; LGA-12_L2.0-W2.0-P0.50-BL; MPN LIS2DW12TR; LCSC Part C189624
U6: TP4056-42-ESOP8; SOIC-8-1EP_3.9x4.9mm_P1.27mm_EP2.41x3.3mm_ThermalVias; LCSC C16581

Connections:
+3V3: C1.1, C3.1, C4.2, C6.1, C7.1, C8.1, Q1.1 (G), Q2.1 (G), R8.1, R10.1, U1.2 (VOUT), U3.3 (VDD/VDDA), U5.9 (VDD), U5.10 (VDDIO)
+5V: C10.1, C11.1, D3.1, J2.2, J3.2, R1.1, R9.1, R11.1, U4.3 (VOUT)
+BATT: C9.1, C13.1, D1.2, J5.1, L1.1, R6.1, U4.7 (VIN), U6.5 (BAT)
/CS: U3.14 (PB0), U5.2 (CS)
/EN: Q3.3 (D), R6.2, U4.5 (EN)
/HV_SCL: J2.4, Q2.3 (D), R11.2
/HV_SDA: J2.3, Q1.3 (D), R9.2
/INT: U3.10 (PA4), U5.12 (INT1)
/MISO: U3.12 (PA6), U5.3 (SDO/SA0)
/MOSI: U3.13 (PA7), U5.4 (SDA/SDI/SDO)
/NRST: C2.1, S1.1 (A), U3.5 (PF2-NRST)
/SCK: U3.11 (PA5), U5.1 (SCL/SPC)
/SCL: Q2.2 (S), R10.2, U3.28 (PB8)
/SDA: Q1.2 (S), R8.2, U3.27 (PB7)
/SWC: J1.3, TP1.1, U3.21 (PA14-BOOT0)
/SWD: J1.2, U3.20 (PA13)
GND: C1.2, C2.2, C3.2, C4.1, C5.2, C6.2, C7.2, C8.2, C9.2, C10.2, C11.2, C12.1, C13.2, J1.4, J2.1, J3.1, J4.A12 (GND), J4.B12 (GND), J4.S1 (SHIELD), J5.2, Q3.2 (S), R2.2, R4.2, R5.2, R7.2, R12.2, S1.2 (B), U1.1 (GND), U3.4 (VSS/VSSA), U4.1 (GND), U4.6 (MODE), U5.6 (GND), U5.7 (RES), U5.8 (GND), U6.1 (TEMP), U6.3 (GND), U6.6 (~STDBY), U6.9 (EPAD)
unnamed: D2.1, R3.1
unnamed: F1.1, J4.A9 (VBUS), J4.B9 (VBUS)
unnamed: J4.A5 (CC1), R4.1
unnamed: J4.B5 (CC2), R5.1
unnamed: Q3.1 (G), R12.1, R13.2
unnamed: C5.1, D1.3, U1.3 (VIN)
unnamed: R1.2, R2.1, U4.4 (FB)
unnamed: L1.2, U4.2 (SW)
unnamed: R7.1, U6.2 (PROG)
unnamed: R3.2, U6.7 (~CHRG)
VBUS: C12.2, D1.1, D2.2, D3.2, F1.2, R13.1, U6.4 (V_{CC}), U6.8 (CE)

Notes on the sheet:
boost converter
level shifters
connectors
battery + charging
accelerometer
microcontroller
5V rail management
microcontroller IO

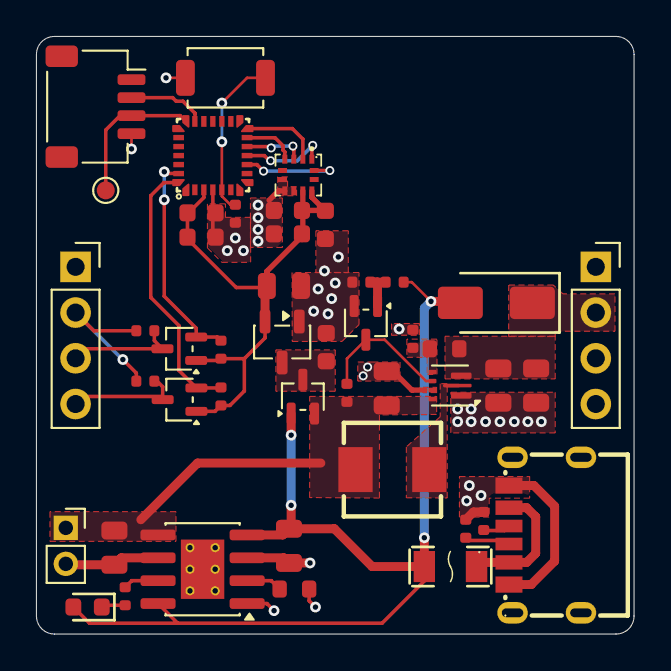
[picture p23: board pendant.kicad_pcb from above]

Board: 4 copper layers, 33.2 x 33.2 mm, 46 parts (0 on the bottom side), 28 nets.

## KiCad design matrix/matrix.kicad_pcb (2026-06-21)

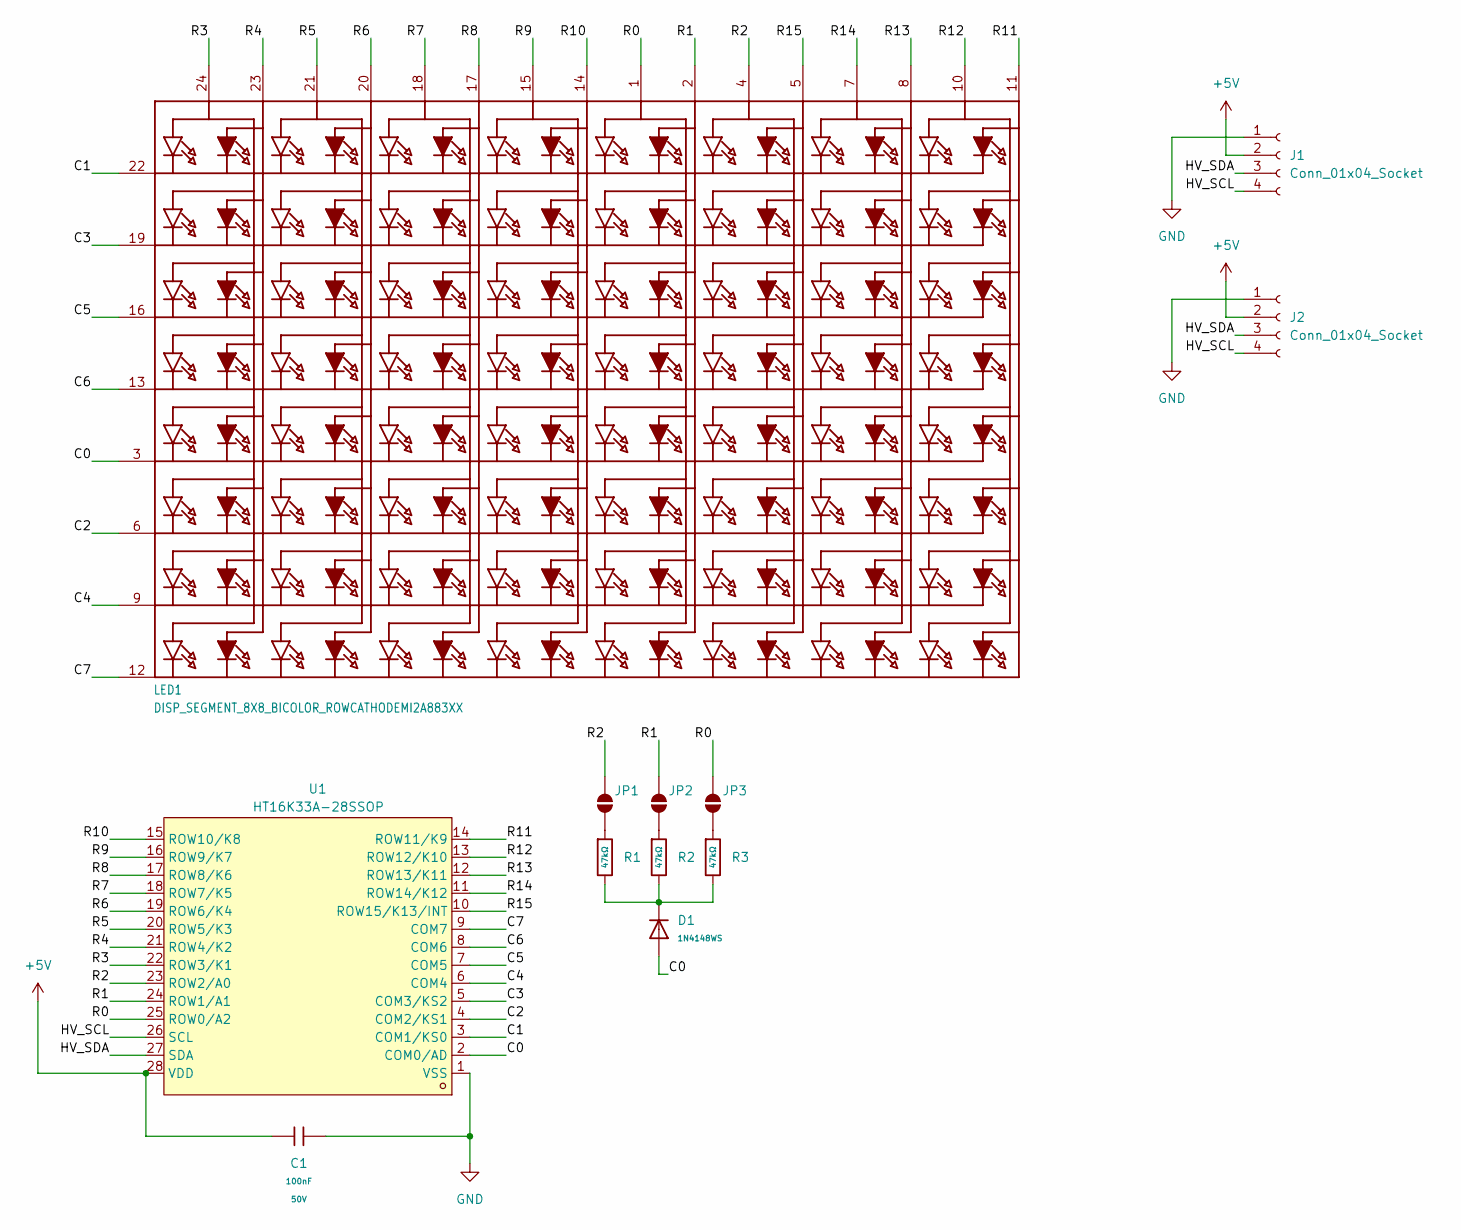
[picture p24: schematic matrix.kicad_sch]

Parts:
C1: 100nF; C_0603; Voltage Rated 50V; Tolerance ±10%; Part CC0603KRX7R9BB104; LCSC C14663
D1: 1N4148WS; D_SOD-323; Forward Voltage (Vf@If) 1.25V@150mA; Reverse Voltage (Vr) 100V; Part 1N4148WS; LCSC C2128
J1, J2: Conn_01x04_Socket; PinSocket_1x04_P2.54mm_Vertical
JP1, JP2, JP3: SolderJumper_2_Open; SolderJumper-2_P1.3mm_Open_RoundedPad1.0x1.5mm
LED1: DISP_SEGMENT_8X8_BICOLOR_ROWCATHODEMI2A883XX; SEGMENT_BICOL_BL-M12A883XX
R1, R2, R3: 47kΩ; R_0603; Overload Voltage (Max) 75V; Tolerance ±1%; Part 0603WAF4702T5E; LCSC C25819
U1: HT16K33A-28SSOP; SSOP-28_3.9x9.9mm_P0.635mm; LCSC Part C5444738

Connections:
+5V: C1.1, J1.2, J2.2, U1.28 (VDD)
/C0: D1.2, LED1.3 (K5), U1.2 (COM0/AD)
/C1: LED1.22 (K1), U1.3 (COM1/KS0)
/C2: LED1.6 (K6), U1.4 (COM2/KS1)
/C3: LED1.19 (K2), U1.5 (COM3/KS2)
/C4: LED1.9 (K7), U1.6 (COM4)
/C5: LED1.16 (K3), U1.7 (COM5)
/C6: LED1.13 (K4), U1.8 (COM6)
/C7: LED1.12 (K8), U1.9 (COM7)
/HV_SCL: J1.4, J2.4, U1.26 (SCL)
/HV_SDA: J1.3, J2.3, U1.27 (SDA)
/R0: JP3.2 (B), LED1.1 (A9), U1.25 (ROW0/A2)
/R1: JP2.2 (B), LED1.2 (A10), U1.24 (ROW1/A1)
/R2: JP1.2 (B), LED1.4 (A11), U1.23 (ROW2/A0)
/R3: LED1.24 (A1), U1.22 (ROW3/K1)
/R4: LED1.23 (A2), U1.21 (ROW4/K2)
/R5: LED1.21 (A3), U1.20 (ROW5/K3)
/R6: LED1.20 (A4), U1.19 (ROW6/K4)
/R7: LED1.18 (A5), U1.18 (ROW7/K5)
/R8: LED1.17 (A6), U1.17 (ROW8/K6)
/R9: LED1.15 (A7), U1.16 (ROW9/K7)
/R10: LED1.14 (A8), U1.15 (ROW10/K8)
/R11: LED1.11 (A16), U1.14 (ROW11/K9)
/R12: LED1.10 (A15), U1.13 (ROW12/K10)
/R13: LED1.8 (A14), U1.12 (ROW13/K11)
/R14: LED1.7 (A13), U1.11 (ROW14/K12)
/R15: LED1.5 (A12), U1.10 (ROW15/K13/INT)
GND: C1.2, J1.1, J2.1, U1.1 (VSS)
unnamed: D1.1, R1.2, R2.2, R3.2
unnamed: JP1.1 (A), R1.1
unnamed: JP2.1 (A), R2.1
unnamed: JP3.1 (A), R3.1

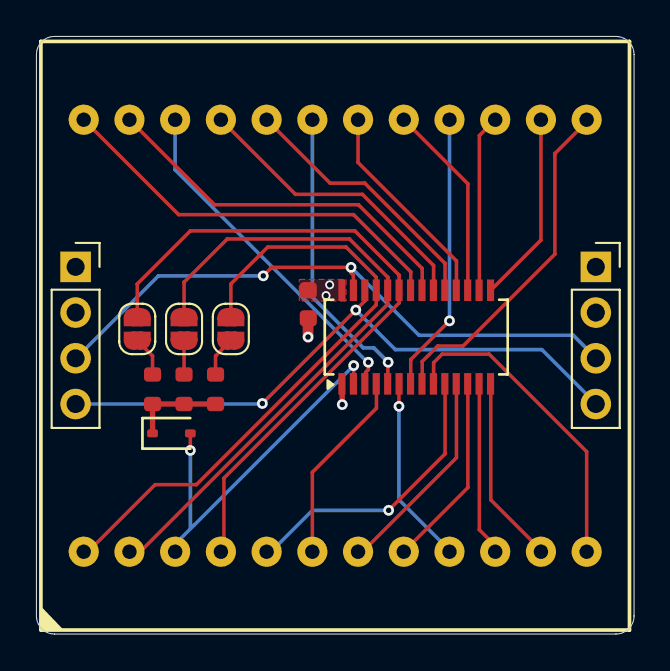
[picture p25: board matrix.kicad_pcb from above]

Board: 4 copper layers, 33.2 x 33.2 mm, 12 parts (0 on the bottom side), 32 nets.

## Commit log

2026-06-21 feat: journal, pcb, prod files
    [bom.csv, designators.csv, matrix-bom.csv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]
2026-06-26 feat: power fixes
    [pendant.kicad_pcb, pendant.kicad_sch]
2026-06-29 feat: update pcb + readme
2026-06-29 feat: other changes
    [bom.csv, designators.csv, pendant-bom.csv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]
